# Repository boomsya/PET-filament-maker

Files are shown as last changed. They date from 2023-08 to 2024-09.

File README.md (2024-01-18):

# Bottle PET filament maker for 3D printers

based on maker https://electronoobs.com/eng_arduino_tut174.php (really think it is not works)
but have some additional features like:
1. forward/reverse direction of motor
2. changed PID regulator to other library
3. added sensor of filament ending
4. deleted PID parameters configuration (leave only temperature configuring)
5. added counting length of filament maked (cm)
6. forward motor steps = 1/16 and revers = 1/1
7. motor activated only when temperature is >= 94% of target
8. and many others improvements based on actual device usage
9. speed controlling with rotary
10. rotary encoder more and more stable controlling when rotating
11. emergency stop motor when heater temperature more than 255c and if heater temperature more than 255 - heating is disabled
12. added filter to temperature sensor - less noise in measurement
13. much better PID parameters for 40W 12V heater. Setpoint = 222C and temperature bouncing in range 220...227C
14. I builded second machine and mechanically some different. So have some code modifications (```#define MACHINE2```)

At now firmware works at Arduino Nano (atmega168) and takes 99% of avaliable space. 
Used cheap PSU 250W.

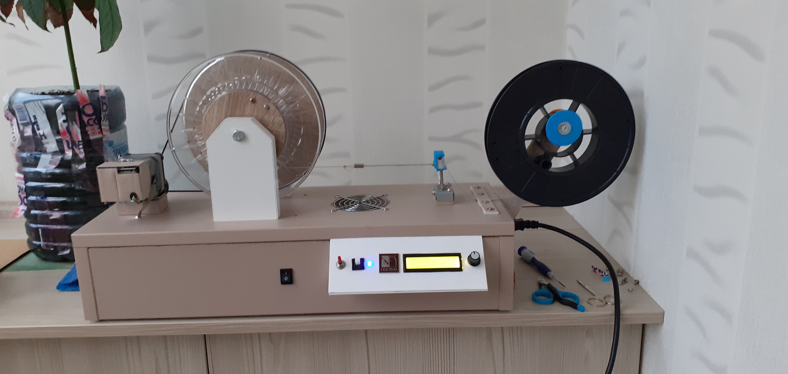
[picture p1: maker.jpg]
pet filament maker


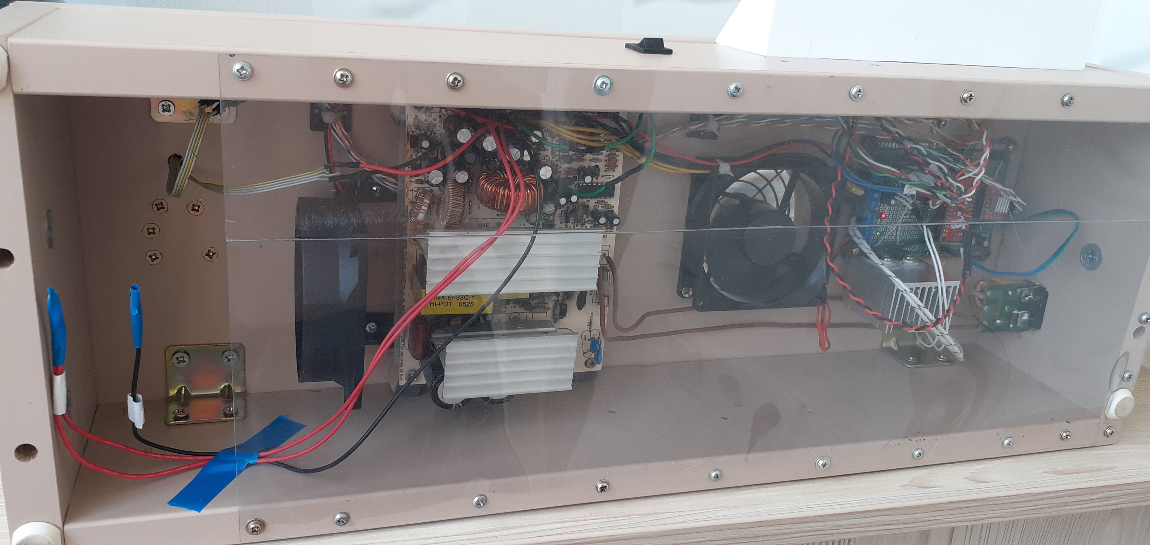
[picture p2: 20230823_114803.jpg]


Result:
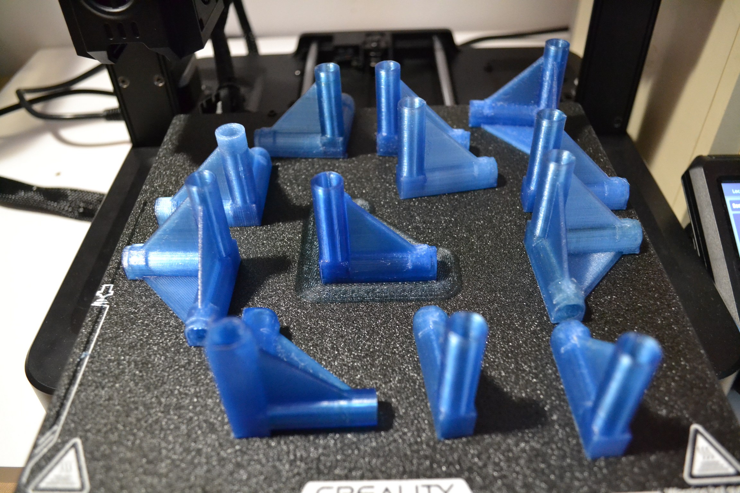
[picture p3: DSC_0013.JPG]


# Stand with Ukraine! -> [United24](https://u24.gov.ua/)

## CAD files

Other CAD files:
sketchup.skp

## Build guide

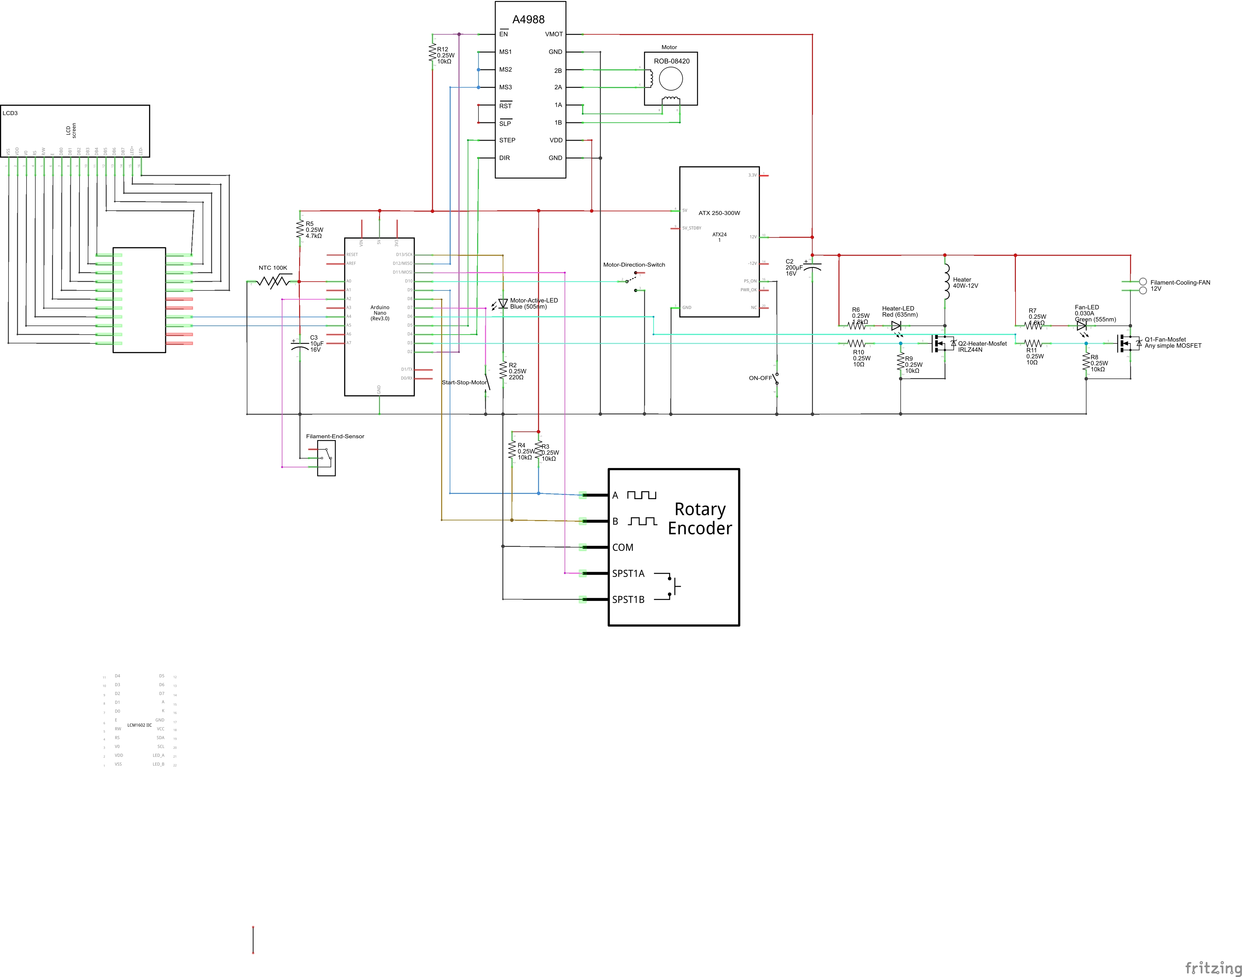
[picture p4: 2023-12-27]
filament maker - scheme.jpg

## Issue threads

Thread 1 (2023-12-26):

Errors Compiling

Gokuh1980, 2023-12-26:
Hi! did you compile the code without errors? because i´ve installed all the libraries and hace errors with the filter,

`//#define MACHINE2 //melting 2

#include <Bounce2.h>

//screen settings
#include <Wire.h>
#include <LiquidCrystal_I2C.h>
LiquidCrystal_I2C lcd(0x27, 16, 2); //sometimes the address is 0x3f
/* i2c LCD Module ==> Arduino
  * SCL ==> A5
  * SDA ==> A4
  * Vcc ==> Vcc (5v)
  * Gnd ==> Gnd */

//configuring I/O pins
const int PWM_heat_pin = 3; //for PWM signal to MOSFET (the BJT npn with pullup)
const int fan_pin = 6; //fan control
const int enable_disable_motor_button_pin = 7; //motor on-off button
const int clk_pin = 8; //clk pin from encoder
const int data_pin = 9; //pin data from encoder
const int dir_button_pin = 10; //pin of the motor rotation direction switch
const int rotary_button_pin = 11; //pin of the encoder button
const int microstep_pin = 12; //activation 1/16 step
const int LED_pin = 13; //LED indication of motor activation
const int filament_end_pin = A2; //tape presence sensor
const int EN_pin = 2; //on A4988
const int DIR_pin = 4; //on A4988
const int STEP_pin = 5; //on A4988

//setting up the thermistor
#include <thermistor.h> //install ThermistorLibrary by Miguel Califa
// Thermistor object
THERMISTOR therm1(A0, // Analog pin
                       10000, // Nominal resistance at 25 ºC
                       3950, //thermistor's beta coefficient
                       10000); // Value of the series resistor
//setting up the stepper motor
#include <AccelStepper.h>//install AccelStepper by Mike McCauley
AccelStepper stepper1(1, STEP_pin, DIR_pin); // (Type of driver: with 2 pins, STEP, DIR)

//variable temperatures
#include "GyverPID.h" //install lib ByverPID by AlexGyver
GyverPID regulator(1, 256, 1.4, 10);
#include "GyverFilters.h" //install the GyverFilters library by AlexGyver
GMedian<10, int> filtered_temperature; //filter
int set_temperature = 222; //Temperature value for washing. Fill in the 0 and use it using the rotary encoder
float temperature_read = 0;//current read temperature
float last_temperature_read = -100;//prev. reading temperature
int last_set_temperature = 0;
bool temperature_riched = false; //has the temperature reached the permissible value
bool last_temperature_riched = true; //prev. status whether the temperature has reached the permissible value

unsigned long Time, last_LCDdrawTime = 0;
byte rotary_button_pressed = 0;//button pressed
byte active_menu = 0;//menu activated
bool menu_changed = true;//sign that the menu has changed in order to draw it

//change the finished stitches
int filament_ended = 1;//sign that the tape has ended: 1 = no tape, 0 = tape available
int last_filament_ended = 0;//prev. tape end status
unsigned long filament_ended_time = 0;

//Functions for assigning a rotary encoder
int clk_State;
int dt_State;
static uint8_t prevNextCode = 0;
static uint16_t store = 0;

//changes for rock motor
byte motor_direction;//direction of motor rotation 1 = winding, 0 = winding
byte last_motor_direction;//prev. motor rotation direction

#define max_speed 1000.0 //maximum speed

const float speeds_percent_arr[7] = {0.0, 6.0, 8.0, 10.0, 16.0, 24.0, 48.0};

Bounce2::Button start_stop_button = Bounce2::Button();
bool stepper_motor_activated = false;//motor activated
bool last_stepper_motor_activated = false;//prev. status whether the motor is activated
float rotating_speed = 0; // rotating speed
float last_rotating_speed = 0;//prev. rotational speed
byte current_speed_idx = 3;//current default rotation speed

//count count. drawn rod
long cm = 0;
long last_cm = -1;
#ifndef MACHINE2
   #define steps_in_cm 1357
#endif
#ifdef MACHINE2
   #define steps_in_cm 629
#endif

void setup() {
   pinMode(EN_pin, OUTPUT); // control pin on-off motor
   digitalWrite(EN_pin, HIGH);//disable the motor by default
   pinMode(fan_pin, OUTPUT);
   digitalWrite(fan_pin, LOW);//disable the fan by default
   stepper1.setMaxSpeed(max_speed);//set the maximum motor speed
   //pinMode(enable_disable_motor_button_pin, INPUT_PULLUP); //motor on-off button
   start_stop_button.attach(enable_disable_motor_button_pin, INPUT_PULLUP);
   start_stop_button.interval(50);
   start_stop_button.setPressedState(LOW);

   pinMode(microstep_pin, OUTPUT);
   digitalWrite(microstep_pin, LOW);//full step

   pinMode(LED_pin, OUTPUT);//indication of motor activation
   digitalWrite(LED_pin, LOW);

   pinMode(PWM_heat_pin, OUTPUT);
   analogWrite(PWM_heat_pin, 0);

   pinMode(dir_button_pin, INPUT_PULLUP);//motor rotation direction switch
   motor_direction = digitalRead(dir_button_pin);
   last_motor_direction = 1 - motor_direction;

   pinMode(rotary_button_pin, INPUT_PULLUP);//encoder button
   pinMode(data_pin, INPUT);//encoder pin data
   pinMode(clk_pin, INPUT);//clk encoder pin

   pinMode(filament_end_pin, INPUT_PULLUP);//tape presence sensor
   filament_ended = digitalRead(filament_end_pin);
   last_filament_ended = 1 - filament_ended;

   TCCR2B = TCCR2B & B11111000 | 0x03;//pin D3 and D11 PWM frequency 928.5 Hz

   clk_State = (PINB & B00000001); //remember the initial state of the rotary encoder
   dt_State = (PINB & B00000010); //remember the initial state of the rotary encoder

   PCICR |= (1 << PCIE0); //enable PCMSK0 scan
   PCMSK0 |= (1 << PCINT0); //set an interrupt on pin D8 when the value changes
   PCMSK0 |= (1 << PCINT1); //set an interrupt on pin D9 when the value changes
   PCMSK0 |= (1 << PCINT2); //set an interrupt on pin D10 when the value changes
   PCMSK0 |= (1 << PCINT3); //set an interrupt on pin D11 when the value changes

   lcd.init();
   lcd.backlight();

   regulator.setDirection(NORMAL);
   regulator.setLimits(0, 255);
   regulator.setpoint = set_temperature;
}

void loop() {
   //Temperature values are readable immediately
   temperature_read = filtered_temperature.filtered(therm1.analog2temp()); //read the temperature

   //is there a tape
   filament_ended = digitalRead(filament_end_pin);

   Time = millis(); //working hour

   start_stop_button.update();

   if (start_stop_button.pressed()) {//the button is pressed
     stepper_motor_activated = !stepper_motor_activated;
     if (stepper_motor_activated) { //motor just turned on
       if ((filament_ended == 1) && (motor_direction == 1)) {
         stepper_motor_activated = 0; //if there is no rod, we don’t start
       }
       if ((stepper_motor_activated == true) && (last_stepper_motor_activated == false)){ //motor just turned on
         stepper1.setCurrentPosition(0);
         cm = 0;
         last_cm = -1;
         last_stepper_motor_activated = true;
       }
     } else { // just turned on the engine
       last_stepper_motor_activated = false;
     }
   }

   //delay the end of the tape
   if (stepper_motor_activated && (motor_direction == 1)) {
     if (filament_ended == 1) { //just ended = detect when exactly
       if (filament_ended_time == 0) {
         filament_ended_time = Time;
       }
     } else {
       filament_ended_time = 0;
     }

     if ((filament_ended_time == 0) || (Time - filament_ended_time < 44000)) {
       filament_ended = 0; //we say that until the tape ends within 40 seconds after its actual end, so that the tail melts more
     }
   }
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
boomsya, 2023-12-26:
some versions before I maked this algorhytm. Here is 2-3 lines of code. In my case every 6 meters I have  real +3% of speedup of winding because every layer of filament is +1.75mm of radius. But new features will goes to 104% of code space :( and I have removed this feature.
And second - after first layer filament try to wind in center :) and I have one perfect layer and other length is like mountain (cant find right word of this, sorry). But I have measure thickness of filament - all ok, because I wind on slow speed and I have some reserve for speedup. So it is not problem as you and me think :)

I have use 5 (34 gramm filament) or 6 (43 gramm filament) litres bottles. Is variable from 10 to 15 metres of filament. You need to play with `steps_in_cm` constant for right calculate of length.

Many peoples in my house leave bottles to me and bottles have the thinkess from 0.1mm to 0.25mm. Very good when is .25 because I have more filament in gramms :)

And last - you need to change stripe width according to bottle plastic thinkess!!! I can make some photos of my bottle cutter and how I regulate width of stripes according to thinkess if you need.

boomsya, 2023-12-26:
If you interrested, maybe you want to view my new repository (DIY filament dryer) https://github.com/boomsya/filament-dryer

Gokuh1980, 2023-12-26:
Excelent, i understand your explanation, i´ve just started the construction of this pultruder.
Could you explain to me the steps_in_cm constant?
#ifndef MACHINE2
  #define steps_in_cm 1357
#endif
#ifdef MACHINE2
  #define steps_in_cm 629
#endif
you only use this to show % in advance of the process or does other function?

i would love to see photos of your cutter. i understand the issue with strip witdh vs wide, i´ve seen one calculator online.

some filament pultruders put the cutter right in front of the heater, what do you think of this?

btw nice filament dryer!!!

boomsya, 2023-12-26:
I have two filament maker machines. Cogs on drives is different. So winded length of filament is different and if I uncomment `#define MACHINE2` then compiler works with `#ifdef MACHINE2` source code. In other case compiler works with `#ifndef MACHINE2` source code.
When I make some changes I have upload new firmware into two Arduinos with different "configs".
This affects only to calculating length of maked filament.

I never use calculator because (easy to talk on native language, and some hard on english :) ) you have some diameter of hile in extruder, it is not 1.75mm and can be 1.8mm and calculating will be wrong. Best solution is when you have some thinkess (example is 0.15mm) of bottle and makes (for example) width of stripe 10mm and when you wind filament you can see what stripe fold in O-ring tube (real O) - this is good. But if you make 9mm width - you have almost O-ring tube (for example 270 degrees only), and if you make 12mm width - this stripe stucks in extruder or you need more slow down winding or increase temperature for make stripe more elastic.
I am always use 222C. But if I see what the filament is stretched very hard (beetwen babine and extruder) - I slowdown speed or increase temperature to 232-236C. For understanding this - I play on stretched filament like on guitar :) if I hear song :) so I need to make life easier to motor :)
On ptohos you will se how I regulate width.

"some filament pultruders put the cutter right in front of the heater, what do you think of this?" - If you mean about cutter so I have seen this but you never can cut bottle automatically without problems. So I make strips and wind to DIY babines (from plastic babines but make only 15mm of width) and this babine put before heater.

boomsya, 2023-12-26:
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

boomsya, 2023-12-26:
final version of machine:

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

Gokuh1980, 2023-12-26:
Ohhh wowwww!!! U left me speechless!!! Thank you so much for your explanations! I'll take every recomendation you made! In a couple of months when the heatblock, heater and thermistor arrives i will show you my results! (They are really expensive in my country... Argentina).

boomsya, 2023-12-27:
yes, you right. Potentiometer I removed in some version of fimware ago because is make some noise in resistance. I mean potentiometer is not very good quality and resistance changing continiolusly +-100 Ohm. So speed of motor changing too. So I was rewrite code to change speed with encoder.
Think I need to update scheme. Thanks.

boomsya, 2023-12-27:
and I forget - as you see - stripe from babine goes under panel (with 4 bolts) and after it he goes to heater. So, inside this panel I have sensor of "end of filament". It is like button (from old DVD), like this:
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

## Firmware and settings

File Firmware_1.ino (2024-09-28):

#define MACHINE2 //плавілка 2 - та що з підсвіткою колеса намотки

#include <Bounce2.h>

//настройка екранчика
#include <Wire.h> 
#include <LiquidCrystal_I2C.h>
LiquidCrystal_I2C lcd(0x27, 16, 2); //иногда адрес 0x3f
/* i2c LCD Module ==>  Arduino
 * SCL            ==>  A5
 * SDA            ==>  A4
 * Vcc            ==>  Vcc (5v)
 * Gnd            ==>  Gnd     */

//настройка пинов ввода-вівода
const int PWM_heat_pin                    = 3;  //для PWM сигнала на MOSFET (the BJT npn with pullup)
const int fan_pin                         = 6;  //управление вентилятором
const int enable_disable_motor_button_pin = 7;  //кнопка вкл-вікл мотор
const int clk_pin                         = 8;  //пин clk от енкодера
const int data_pin                        = 9;  //пин data от енкодера
const int dir_button_pin                  = 10; //пин переключателя направления вращения мотора
const int rotary_button_pin               = 11; //пин кнопки енкодера
const int microstep_pin                   = 12; //активация 1/16 шага
const int LED_pin                         = 13; //светодиодная индикация активации мотора
const int filament_end_pin  = A2; //датчик наличия ленті
const int EN_pin            = 2; //на A4988
const int DIR_pin           = 4; //на A4988
const int STEP_pin          = 5; //на A4988

//настройка термистора
#include <thermistor.h> //установить ThermistorLibrary by Miguel Califa
thermistor therm1(A0, 0); //подключить термистор на ножку A0, 0 represents TEMP_SENSOR_0 ( configuration.h for more)

//настройка шагового моторчика
#include <AccelStepper.h>//установить AccelStepper by Mike McCauley
AccelStepper stepper1(1, STEP_pin, DIR_pin); // (Type of driver: with 2 pins, STEP, DIR)

//змінні температурі
#include "GyverPID.h" //установить либу ByverPID by AlexGyver
GyverPID regulator(1, 256, 1.4, 10);
#include "GyverFilters.h" //установить лібу GyverFilters by AlexGyver
GMedian<10, int> filtered_temperature; //фильтр
byte set_temperature = 224; //Значення температури за замовчуванням. Керуйте ним за допомогою поворотного енкодера
float temperature_read = 0;//текущая считанная температура
float last_temperature_read = -100;//пред. считанная температура
byte last_set_temperature = 0;
bool temperature_riched = false; //достигла ли температура допустимого значения
bool last_temperature_riched = true; //пред. статус достигла ли температура допустимого значения

unsigned long Time, last_LCDdrawTime = 0;
byte rotary_button_pressed = 0;//кнопка натиснута
byte active_menu = 0;//меню активовано
bool menu_changed = true;//признак что сменилось меню, чтобі отрисовать его

//змінні закінчення стрічки
int filament_ended = 1;//признак что лента закончилась: 1 = ленті нету, 0 = лента есть
int last_filament_ended = 0;//пред. статус заканчивания ленті
unsigned long filament_ended_time = 0;

//Функції для визначення стану поворотного енкодера
int clk_State;
int dt_State;
static uint8_t prevNextCode = 0;
static uint16_t store = 0;

//змінні для крокового мотора
byte motor_direction;//направление кручения мотора 1 = наматіваем, 0 = сматіваем
byte last_motor_direction;//пред. направление кручения мотора

#define max_speed 1000.0 //максимальна швидкість

const float speeds_percent_arr[7] = {0.0, 6.0, 8.0, 10.0, 16.0, 24.0, 48.0};

Bounce2::Button start_stop_button = Bounce2::Button();
bool stepper_motor_activated = false;//чи активовано мотор
bool last_stepper_motor_activated = false;//пред. статус активирован ли мотор
float rotating_speed = 0;//поточна швидкість обертання
float last_rotating_speed = 0;//пред. скорость вращения
byte current_speed_idx = 6;//текущая скорость вращения по умолчанию

//подсчет кол. вітянутого прутка
long cm = 0;
long last_cm = -1;
#ifndef MACHINE2
  #define steps_in_cm 1357
#endif
#ifdef MACHINE2
  #define steps_in_cm 629
#endif

void setup() {
  pinMode(EN_pin, OUTPUT);//пин управления вкл-вікл мотор
  digitalWrite(EN_pin, HIGH);//отключаем мотор по умолчанию
  pinMode(fan_pin, OUTPUT);
  digitalWrite(fan_pin, LOW);//отключаем вентилятор по умолчанию
  stepper1.setMaxSpeed(max_speed);//задаем максимальную скорость мотора
  //pinMode(enable_disable_motor_button_pin, INPUT_PULLUP);//кнопка вікл-вікл мотор
  start_stop_button.attach(enable_disable_motor_button_pin, INPUT_PULLUP);
  start_stop_button.interval(50);
  start_stop_button.setPressedState(LOW);
  
  pinMode(microstep_pin, OUTPUT);  

  pinMode(LED_pin, OUTPUT);//индикация активации мотора
  digitalWrite(LED_pin, LOW);
    
  pinMode(PWM_heat_pin, OUTPUT);
  analogWrite(PWM_heat_pin, 0);

  pinMode(dir_button_pin, INPUT_PULLUP);//переключатель направления вращения мотора 
  motor_direction = digitalRead(dir_button_pin);
  last_motor_direction = 1 - motor_direction;
  if (motor_direction == 0) { //сматіваем
    digitalWrite(microstep_pin, LOW);//полній шаг
  } else {
    digitalWrite(microstep_pin, HIGH);//1/16 шага
  }

  pinMode(rotary_button_pin, INPUT_PULLUP);//кнопка енкодера
  pinMode(data_pin, INPUT);//data пин енкодера
  pinMode(clk_pin, INPUT);//clk пин енкодера
  
  pinMode(filament_end_pin, INPUT_PULLUP);//датчик наличия ленті
  filament_ended = digitalRead(filament_end_pin);
  last_filament_ended = 1 - filament_ended;

  TCCR2B = TCCR2B & B11111000 | 0x03;//ножка D3 и D11 PWM частота 928.5 Hz

  clk_State = (PINB & B00000001); //запоминаем начальное состояние поворотного енкодера
  dt_State  = (PINB & B00000010); //запоминаем начальное состояние поворотного енкодера

  PCICR |= (1 << PCIE0);   //enable PCMSK0 scan                                                 
  PCMSK0 |= (1 << PCINT0); //устанавливаем прерівание на пине D8 при смене значения
  PCMSK0 |= (1 << PCINT1); //устанавливаем прерівание на пине D9 при смене значения
  PCMSK0 |= (1 << PCINT2); //устанавливаем прерівание на пине D10 при смене значения
  PCMSK0 |= (1 << PCINT3); //устанавливаем прерівание на пине D11 при смене значения

  lcd.init();
  lcd.backlight();

  regulator.setDirection(NORMAL);
  regulator.setLimits(0, 255);
  regulator.setpoint = set_temperature;
}

void loop() {
  //есть ли лента
  filament_ended = digitalRead(filament_end_pin);

  Time = millis(); //поточний час

  start_stop_button.update();

  if (start_stop_button.pressed()) {//кнопка нажата
    stepper_motor_activated = !stepper_motor_activated;
    if (stepper_motor_activated) { //только что включили мотор
      if ((filament_ended == 1) && (motor_direction == 1)) { 
        stepper_motor_activated = 0; //если нет прутка - не стартуем
      }
      if ((stepper_motor_activated == true) && (last_stepper_motor_activated == false)){ //только что включили мотор
        stepper1.setCurrentPosition(0);
        cm = 0;
        last_cm = -1;
        last_stepper_motor_activated = true;
      }
    } else { //только что віключили мотор
      last_stepper_motor_activated = false;
    }
  }
  
  if (motor_direction == 1) { //наматіваем
    //откладіваем заканчивание ленті на 41-44 сек
    if (stepper_motor_activated) {
      if (filament_ended == 1) { //только что закончилась = засекаем когда именно
        if (filament_ended_time == 0) {
          filament_ended_time = Time;
        }
      } else {
        filament_ended_time = 0;
      }

      #ifndef MACHINE2
      if ((filament_ended_time == 0) || (Time - filament_ended_time < 44000)) {
        filament_ended = 0; //говорим, что пока лента не закончилась в течении 40 сек после его реального окончания, чтобі хвостик проплавило больше
      }
      #endif
      #ifdef MACHINE2
      if ((filament_ended_time == 0) || (Time - filament_ended_time < 40000)) {
        filament_ended = 0; //говорим, что пока лента не закончилась в течении 40 сек после его реального окончания, чтобі хвостик проплавило больше
      }
      #endif
    }

    //віставляем PWM сигнал для нагрева mosfet на контакт D3
    temperature_read = filtered_temperature.filtered(therm1.analog2temp()); //читаємо значення температури

    if ((filament_ended == 0) && (temperature_read < 250)) { //наматіваем + есть лента + нет перегрева
      regulator.input = temperature_read;
      analogWrite(PWM_heat_pin, regulator.getResultTimer());
      rotating_speed = max_speed * speeds_percent_arr[current_speed_idx] / 100.0; //предварительно считаем скорость мотора, максимум 48%
    } else { //ленті нет, перегрев - не греем
      analogWrite(PWM_heat_pin, 0);
      stepper_motor_activated = false;
    }

    //достигла ли температура необходимого значения (минимум 96% от необходимого)
    temperature_riched = (temperature_read >= (set_temperature * 0.96));

    //включена намотка + включен мотор + (лента закочилась или температура не достигла нужного значения) = віключаем мотор (проверка на то, что нужно греть или нет чуть віше)
    if (stepper_motor_activated && ((filament_ended == 1) || (!temperature_riched) || (temperature_read >= 250))){
      stepper_motor_activated = false;
    }
  } else { //когда сматіваем бабину - не греем
    analogWrite(PWM_heat_pin, 0);
  }

  //текущее состояние
  if (active_menu == 0) {
    if (menu_changed) {
      menu_changed = false;
      lcd.clear();
      lcd.setCursor(0, 0);
      lcd.print("TMP");
      lcd.setCursor(7, 0);
      lcd.print(" -> ");
      lcd.setCursor(0, 1);
      lcd.print("SPD");
      lcd.setCursor(14, 1);
      lcd.print("cm");
    }

    if (last_filament_ended != filament_ended) { //принудительно перерисовіваем данніе если статус ленті поменялся
      last_LCDdrawTime = 0;
      last_rotating_speed = -1;
      last_motor_direction = 1 - motor_direction;
      last_temperature_read = -100;
    }

    if (Time - last_LCDdrawTime > 1500) {//оновлюємо дисплей
      if (stepper_motor_activated && (motor_direction == 1)) { //якщо мотор крутить і намотує
        cm = floor(stepper1.currentPosition()/steps_in_cm); //лічильник намотаного прутка
      }

      if (last_temperature_riched != temperature_riched) { //рисуем знак достиго ли значение температурі необходимого значения
        lcd.setCursor(8, 0);
        if (temperature_riched) {
          lcd.print("=");
        } else {
          lcd.print("-");
        }
        last_temperature_riched = temperature_riched;
      }

      if (last_filament_ended != filament_ended) {//малюємо чи закінчилася стрічка
        lcd.setCursor(15, 0);
        if (filament_ended == 1) { //стрічка закінчилася
          lcd.print('-');
        } else {
          lcd.print('+');
        }
        last_filament_ended = filament_ended;
      }

      if ((motor_direction == 1) && (last_temperature_read != roundf(temperature_read))) { //рисуем текущую температуру
        lcd.setCursor(5, 0);
        lcd.print("  ");
        lcd.setCursor(4, 0);
        lcd.print((int) temperature_read);
        last_temperature_read = roundf(temperature_read);
      }

      if (last_motor_direction != motor_direction) { //малюємо температуру до якої прагне плавилка
        lcd.setCursor(12, 0);
        lcd.print("  ");
        lcd.setCursor(11, 0);
        if ((motor_direction == 1) && (filament_ended == 0)) { //наматіваем + есть лента
          char tmpstr[3];
          lcd.print(itoa(set_temperature, tmpstr, 10));
        } else { //когда сматіваем бабину - не греем
          lcd.print("0  ");
        }
        if (motor_direction == 0){ //если смативаем то рисуем температуру 0, чтобі мотор не дергался постоянно при смене температурі
          lcd.setCursor(4, 0);
          lcd.print("0  ");
          cm = 0; //показуємо відразу що не рахуємо скільки намотано було
        }
        last_motor_direction = motor_direction;
      }

      if (last_cm != cm) { //счетчик намотаного прутка в сантиметрах
        lcd.setCursor(11, 1);
        lcd.print("   ");
        lcd.setCursor(10, 1);
        lcd.print(cm);
        last_cm = cm;
      }
      
      if (last_rotating_speed != rotating_speed) {//рисуем скорость мотора
        lcd.setCursor(5, 1);
        lcd.print("    ");
        lcd.setCursor(4, 1);
        lcd.print(speeds_percent_arr[current_speed_idx], 0);
        lcd.print('%');
        last_rotating_speed = rotating_speed;
      }

      last_LCDdrawTime = Time;
    }
  } else if (active_menu == 1) { //меню настройка температурі
    if (menu_changed || (set_temperature != last_set_temperature)) {
      lcd.clear();
      lcd.setCursor(0, 0);
      lcd.print("Set temperature");    
      lcd.setCursor(0, 1);
      char tmpstr[3];
      lcd.print(itoa(set_temperature, tmpstr, 10));
      lcd.print("  ");
      menu_changed = false;
    }
    last_set_temperature = set_temperature;
  }

  if (stepper_motor_activated) {//мотор активен
    digitalWrite(LED_pin, HIGH); //светодиод светит
    digitalWrite(EN_pin, LOW); //активируем мотор
    if (motor_direction == 0) { //сматіваем
      digitalWrite(microstep_pin, LOW); //полній шаг
      #ifndef MACHINE2
      rotating_speed = -444;
      #endif
      #ifdef MACHINE2
      rotating_speed = -320;//-469;
      #endif
    } else { //наматіваем
      digitalWrite(microstep_pin, HIGH); //1/16 шага
    }

    if ((motor_direction == 1) && (filament_ended == 0)) {
      digitalWrite(fan_pin, HIGH); //активируем вентилятор
    } else {
      digitalWrite(fan_pin, LOW); //деактивируем вентилятор
    }

    stepper1.setSpeed(rotating_speed);
    stepper1.runSpeed();
  } else {
    digitalWrite(EN_pin, HIGH); //деактивируем мотор
    digitalWrite(fan_pin, LOW); //деактивируем вентилятор
    digitalWrite(LED_pin, LOW); //светодиод вимкнено
  } 
}

//Прерівания для кнопки та поворотного енкодера
ISR(PCINT0_vect) {
  static unsigned long last_interrupt_time = 0;
  static int8_t rot_enc_table[] = {0,1,1,0,1,0,0,1,1,0,0,1,0,1,1,0};

  clk_State = (PINB & B00000001); //состояние clk_pin (D8)
  dt_State  = (PINB & B00000010); //состояние data_pin (D9)

  prevNextCode <<= 2;
  if (dt_State != 0) {
    prevNextCode |= 0x02;
  }
  if (clk_State != 0) {
    prevNextCode |= 0x01;
  }
  prevNextCode &= 0x0f;

  if (rot_enc_table[prevNextCode]) {
    store <<= 4;
    store |= prevNextCode;
    if ((store&0xff)==0x2b) {//проти часової стрілки
      if (active_menu == 0) {//главное меню - тут регулируем скорость
        if (current_speed_idx > 0) { 
          current_speed_idx--; 
          last_LCDdrawTime = 0;
        }
      } else if (active_menu == 1) {//меню управления температурой 
        if (set_temperature > 0) { set_temperature -= 1; }
        regulator.setpoint = set_temperature;
      }
    }
    if ((store&0xff)==0x17) {//по часовій стрілці
      if (active_menu == 0) {//главное меню - тут регулируем скорость
        if (current_speed_idx < 6) {
          current_speed_idx++; 
          last_LCDdrawTime = 0; 
        }
      } else if (active_menu == 1) {//меню управления температурой 
        if (set_temperature <= 242) { set_temperature += 1; }
        regulator.setpoint = set_temperature;
      }
    }
  }

  //кнопка на енкодере нажата
  if ((PINB & B00001000) == 0) { //кнопка на енкодере rotary_button_pin (D11) нажата?
    unsigned long interrupt_time = millis();
    if (interrupt_time - last_interrupt_time > 200){
      rotary_button_pressed = 1;
      last_interrupt_time = interrupt_time;
    }
  } else if (rotary_button_pressed == 1) { //Переходимо послідовно по двум меню з кожним натиском кнопки
    active_menu++;
    if (active_menu > 1) {
      active_menu = 0;
    }
    menu_changed = true;
    last_LCDdrawTime = 0;
    last_rotating_speed = -1;
    last_filament_ended = 1 - filament_ended;
    last_motor_direction = 1 - motor_direction;
    last_temperature_riched = !temperature_riched;
    last_cm = -1;
    rotary_button_pressed = 0;
  }

  //переключатель направления вращения
  if (PINB & B00000100) {
    motor_direction = 1; //наматіваем
  } else {
    motor_direction = 0; //сматіваем
  }
}

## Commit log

2023-10-09 Update Firmware_1.ino
    1. no need speed potentiometer
    2. rotary encoder more more stable controlling
2024-01-12 printing profile with PET plastic on Ender 3 V3 KE
2024-01-18 quality of printed models
2024-08-03 Update Firmware_1.ino
    fixed print target temperature
    [Firmware_1.ino]
2024-09-28 Update Firmware_1.ino
    error finded after code optimization
    [Firmware_1.ino]
